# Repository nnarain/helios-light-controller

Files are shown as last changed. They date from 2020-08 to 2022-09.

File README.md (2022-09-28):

# Helios Light Controller




ESP32 based light strip controller.

Usage
-----

TODO

Hardware
--------

This repo contains schematics and PCB layouts for the ESP light controller.

Install submodules to pull in external KiCAD libraries.

```
$ git submodule update --init --recursive
```

Checkout the [release](https://github.com/nnarain/helios-light-controller/releases) page for KiCAD outputs.

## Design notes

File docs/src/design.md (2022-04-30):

# Design

Full schematics can be viewed here: {{#find schematic}}

To see the bill of materials click here: {{#find ibom}}

{{#find schematic_svg}}

{{#find pcb_top}}

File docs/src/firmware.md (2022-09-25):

For full functionality, some WLED usermods must be initialized.

Use the following platformio overrides:

```ini
[platformio]
default_envs = esp32dev

[env:esp32dev]
board = esp32dev
platform = ${esp32.platform}
platform_packages = ${esp32.platform_packages}
build_unflags = ${common.build_unflags}
build_flags = ${common.build_flags_esp32}
             -D WLED_RELEASE_NAME=ESP32
             -D USERMOD_DALLASTEMPERATURE
             -D USERMOD_DALLASTEMPERATURE_CELSIUS
             -D USERMOD_PWM_FAN
             -D PWM_PIN=16
             -D TACHO_PIN=17
lib_deps = ${esp32.lib_deps}
monitor_filters = esp32_exception_decoder
board_build.partitions = ${esp32.default_partitions}
```

Build the firmware then upload to the controllers (note right now the auto-reset does not work, so put the controller in download mode using the BOOT button)

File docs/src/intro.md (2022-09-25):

# Intro

Helios is a ESP32 based smart LED controller intended to work with [WLED](https://kno.wled.ge/) firmware.

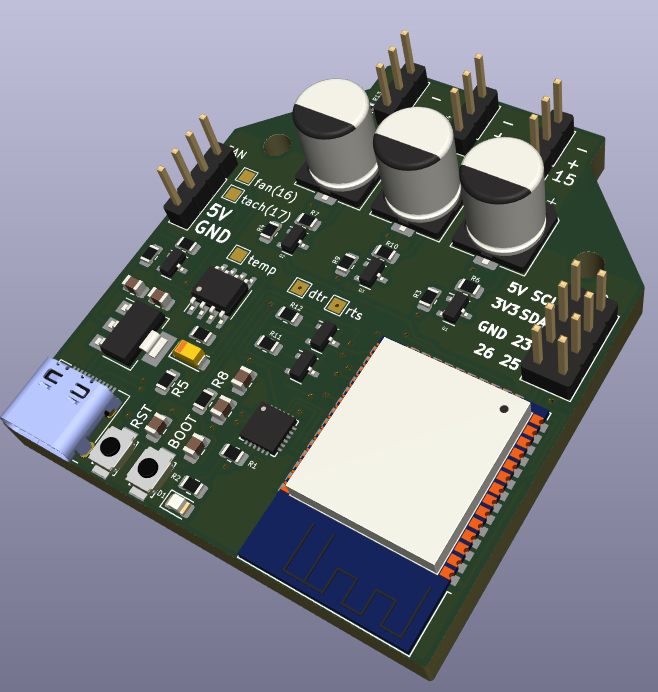
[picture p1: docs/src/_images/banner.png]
image not found!


It features:

* 3x 5V LED output channels
* A PWM fan header (with tachometer feedback)
* I2C and 3x IO breakout
* A USB-C connector and onboard USB-UART adaptor

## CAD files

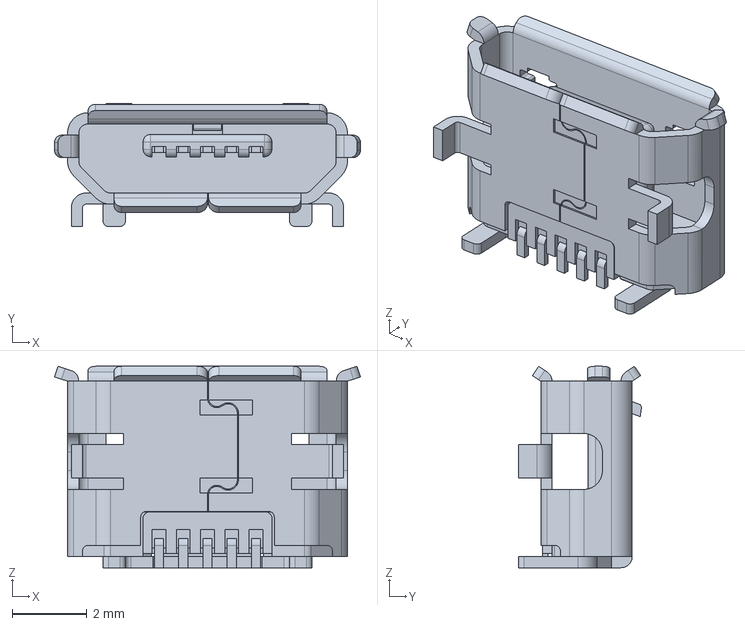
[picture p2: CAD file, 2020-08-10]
design/helios-light-controller/models/usb-b-micro-1050170001.stp
8.20 x 3.30 x 5.40 mm

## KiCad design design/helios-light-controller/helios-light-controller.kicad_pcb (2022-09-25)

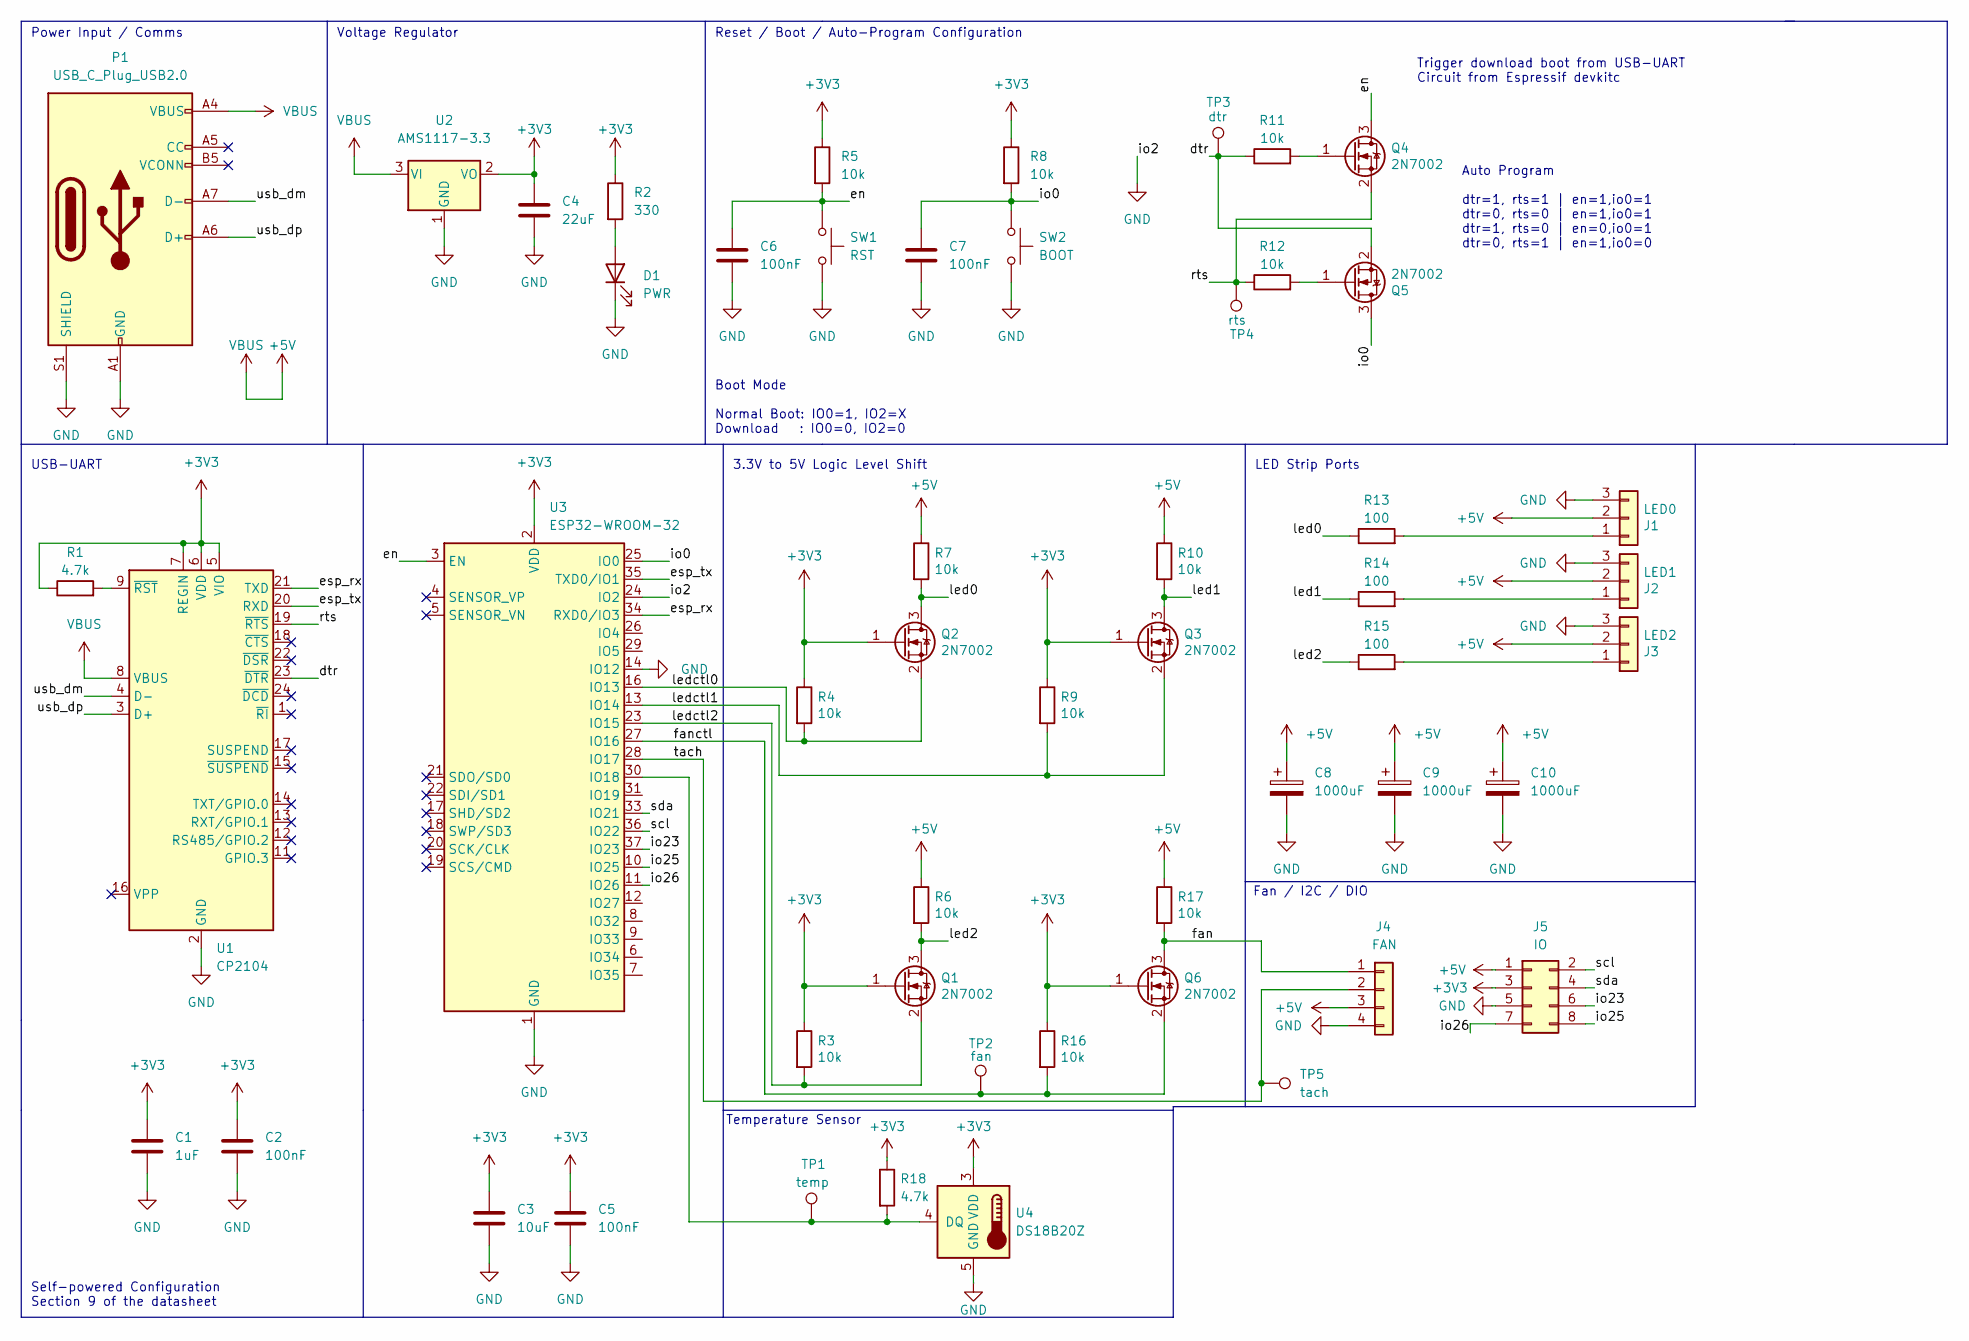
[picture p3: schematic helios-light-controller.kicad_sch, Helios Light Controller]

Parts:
C1: 1uF; C_0805_2012Metric; LCSC C28323
C2, C5, C6, C7: 100nF; C_0805_2012Metric; LCSC C28233
C3: 10uF; C_0805_2012Metric; LCSC C1710
C4: 22uF; CP_EIA-3216-18_Kemet-A; LCSC C116575
C8, C9, C10: 1000uF; CP_Elec_8x10; LCSC C134755
D1: PWR; LED_0805_2012Metric; LCSC C434432
J1: LED0; PinHeader_1x03_P2.54mm_Vertical
J2: LED1; PinHeader_1x03_P2.54mm_Vertical
J3: LED2; PinHeader_1x03_P2.54mm_Vertical
J4: FAN; PinHeader_1x04_P2.54mm_Vertical
J5: IO; PinHeader_2x04_P2.54mm_Vertical
P1: USB_C_Plug_USB2.0; TYPE-C-31-M-04; LCSC C129018
Q1, Q2, Q3, Q4, Q5, Q6: 2N7002; SOT-23; LCSC C8545
R1, R18: 4.7k; R_0805_2012Metric; LCSC C17673
R2: 330; R_0805_2012Metric; LCSC C17630
R3, R4, R5, R6, R7, R8, R9, R10, R11, R12, R16, R17: 10k; R_0805_2012Metric; LCSC C17414
R13, R14, R15: 100; R_0805_2012Metric; LCSC C17408
SW1: RST; TS-1088-AR02016; LCSC C720477
SW2: BOOT; TS-1088-AR02016; LCSC C720477
TP1: temp; TestPoint_Pad_1.5x1.5mm
TP2: fan; TestPoint_Pad_1.5x1.5mm
TP3: dtr; TestPoint_Pad_1.5x1.5mm
TP4: rts; TestPoint_Pad_1.5x1.5mm
TP5: tach; TestPoint_Pad_1.5x1.5mm
U1: CP2104; QFN-24-1EP_4x4mm_P0.5mm_EP2.6x2.6mm; LCSC C47742
U2: AMS1117-3.3; SOT-223-3_TabPin2; LCSC C6186
U3: ESP32-WROOM-32; LCSC C82899
U4: DS18B20Z; SOIC-8_3.9x4.9mm_P1.27mm; LCSC C695837

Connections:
+3V3: C1.1, C2.1, C3.1, C4.1, C5.1, J5.3, Q1.1 (G), Q2.1 (G), Q3.1 (G), Q6.1 (G), R1.1, R2.1, R3.1, R4.1, R5.1, R8.1, R9.1, R16.1, R18.1, U1.5 (VIO), U1.6 (VDD), U1.7 (REGIN), U2.2 (VO), U3.2 (VDD), U4.3 (VDD)
+5V: C8.1, C9.1, C10.1, J1.2, J2.2, J3.2, J4.3, J5.1, P1.A4 (VBUS), P1.A9 (VBUS), P1.B4 (VBUS), P1.B9 (VBUS), R6.1, R7.1, R10.1, R17.1, U1.8 (VBUS), U2.3 (VI); also elsewhere on the board
/dtr: Q5.2 (S), R11.1, TP3.1, U1.23 (~DTR)
/en: C6.1, Q4.3 (D), R5.2, SW1.1, U3.3 (EN)
/esp_rx: U1.21 (TXD), U3.34 (RXD0/IO3)
/esp_tx: U1.20 (RXD), U3.35 (TXD0/IO1)
/fan: J4.1, Q6.3 (D), R17.2; also elsewhere on the board
/fanctl: Q6.2 (S), R16.2, TP2.1, U3.27 (IO16)
/io0: C7.1, Q5.3 (D), R8.2, SW2.1, U3.25 (IO0)
/io23: J5.6, U3.37 (IO23)
/io25: J5.8, U3.10 (IO25)
/io26: J5.7, U3.11 (IO26)
/led0: Q2.3 (D), R7.2, R13.1
/led1: Q3.3 (D), R10.2, R14.1
/led2: Q1.3 (D), R6.2, R15.1
/ledctl0: Q2.2 (S), R4.2, U3.16 (IO13)
/ledctl1: Q3.2 (S), R9.2, U3.13 (IO14)
/ledctl2: Q1.2 (S), R3.2, U3.23 (IO15)
/rts: Q4.2 (S), R12.1, TP4.1, U1.19 (~RTS)
/scl: J5.2, U3.36 (IO22)
/sda: J5.4, U3.33 (IO21)
/tach: J4.2, TP5.1, U3.28 (IO17); also elsewhere on the board
/usb_dm: P1.A7 (D-), U1.4 (D-)
/usb_dp: P1.A6 (D+), U1.3 (D+)
GND: C1.2, C2.2, C3.2, C4.2, C5.2, C6.2, C7.2, C8.2, C9.2, C10.2, D1.1 (K), J1.3, J2.3, J3.3, J4.4, J5.5, P1.A1 (GND), P1.A12 (GND), P1.B1 (GND), P1.B12 (GND), P1.S1 (SHIELD), SW1.2, SW2.2, U1.2 (GND), U1.25 (GND), U2.1 (GND), U3.1 (GND), U3.14 (IO12), U3.15 (GND), U3.24 (IO2), U3.38 (GND), U3.39 (GND), U4.5 (GND); also elsewhere on the board
unnamed: D1.2 (A), R2.2
unnamed: J1.1, R13.2
unnamed: J2.1, R14.2
unnamed: J3.1, R15.2
unnamed: Q4.1 (G), R11.2
unnamed: Q5.1 (G), R12.2
unnamed: R1.2, U1.9 (~RST)
unnamed: R18.2, TP1.1, U3.30 (IO18), U4.4 (DQ)

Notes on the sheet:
Power Input / Comms
Auto Program dtr=1, rts=1 | en=1,io0=1 dtr=0, rts=0 | en=1,io0=1 dtr=1, rts=0 | en=0,io0=1 dtr=0, rts=1 | en=1,io0=0
LED Strip Ports
Self-powered Configuration Section 9 of the datasheet
Temperature Sensor
Fan / I2C / DIO
Trigger download boot from USB-UART Circuit from Espressif devkitc
Reset / Boot / Auto-Program Configuration
USB-UART
Boot Mode Normal Boot: IO0=1, IO2=X Download : IO0=0, IO2=0
3.3V to 5V Logic Level Shift
Voltage Regulator

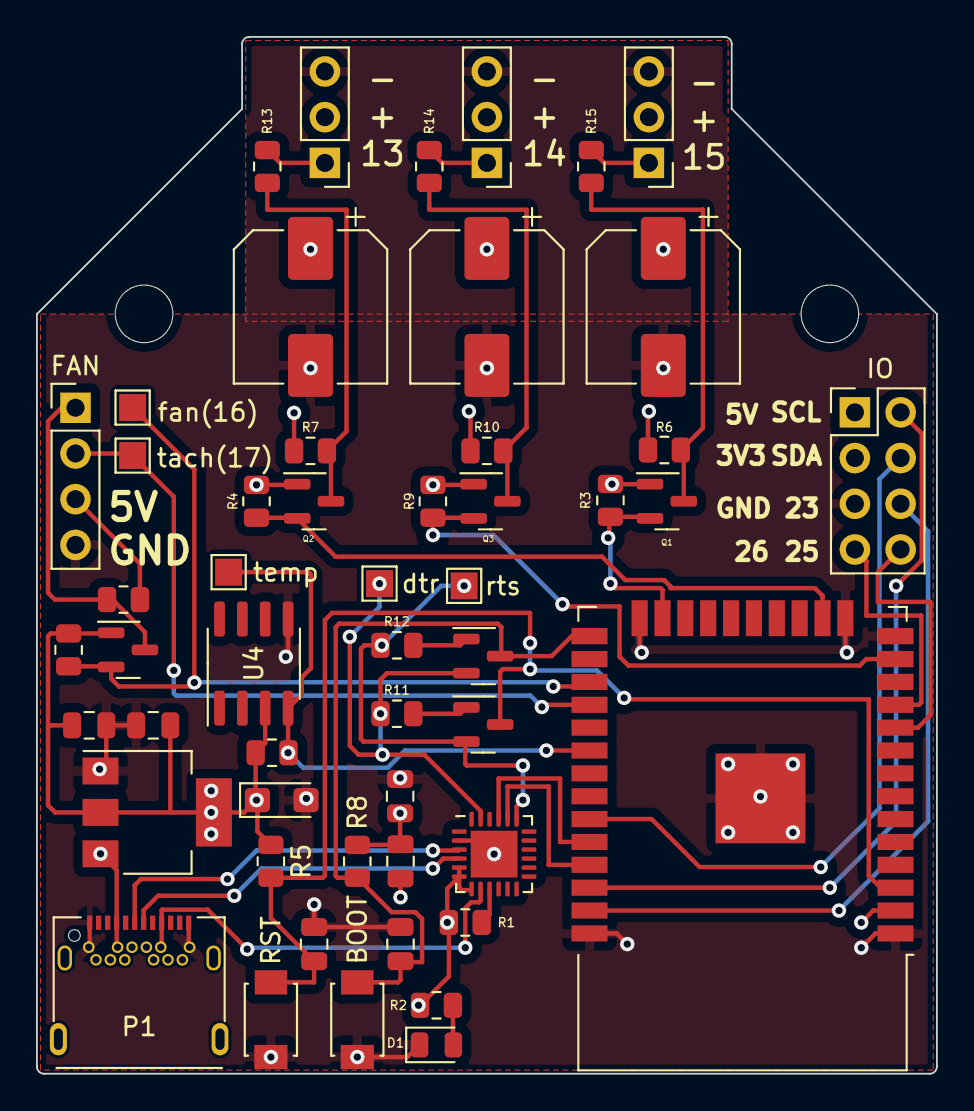
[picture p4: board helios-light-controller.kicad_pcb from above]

Board: 4 copper layers, 50.0 x 57.6 mm, 52 parts (0 on the bottom side), 33 nets.

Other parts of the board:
FAN: FAN; PinHeader_1x04_P2.54mm_Vertical

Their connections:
+5V: FAN.3; also elsewhere on the board
/fan: FAN.1; also elsewhere on the board
/tach: FAN.2; also elsewhere on the board
GND: FAN.4; also elsewhere on the board

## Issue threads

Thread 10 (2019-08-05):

Move ESP01 KiCAD files into repo

nnarain, 2019-08-05:
Currently they use the absolute path on my system,

nnarain, 2019-08-05:
KiCAD project should use relative paths for libraries.

nnarain, 2019-08-05:
Relative paths might not be an option. If not https://aurabindo.in/kicad-tip-component-libraries/

Closed 2019-08-05.

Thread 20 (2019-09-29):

Include ESP8266 KiCAD library in automatic builds

nnarain, 2019-09-29:

nnarain, 2019-10-08:
Resolved by #29.

Closed 2019-10-08.

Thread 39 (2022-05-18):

MTDI (GPIO12) should be pulled down

nnarain, 2022-05-18:
This is one of the "strapping" pins and is used to configure the SPI flash. Currently this is pulled up for one of the level shifters which configures the SPI flash for 1.8V instead of 3.3V.

Closed 2022-09-05.

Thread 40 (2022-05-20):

Temperature sensor

nnarain, 2022-05-20:
Onboard temperature sensor

nnarain, 2022-05-20:
https://github.com/Aircoookie/WLED/tree/main/usermods/Temperature

Closed 2022-09-05.

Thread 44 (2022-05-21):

Reverse voltage protection

nnarain, 2022-05-21:

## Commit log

2019-08-04 Resolves #7. Restore light state after power cycle.
2019-08-04 Resolves #8. Added KiCAD files.
    [esp-light-controller.sch]
2019-08-05 Update pinout for USB connector
    [esp-light-controller.sch]
2019-08-05 Resolves #10. Removed use of absolute paths in project settings.
    [esp-light-controller.sch]
2019-08-08 Resolves #11. Added PCB Layout.
    [esp-light-controller.kicad_pcb, esp-light-controller.sch]
2019-09-29 Resolves #13. KiCAD automation
2019-10-01 NOP schematic update..
2019-10-08 Resolves #29. Added third party KiCAD as a submodule.
    [esp-light-controller.sch]
2020-07-28 Update to surface mount components
    [esp-light-controller.kicad_pcb, esp-light-controller.sch]
2020-07-30 Version 2 design
    [esp-light-controller.kicad_pcb, esp-light-controller.sch, usb-b-micro-1050170001.stp]
2020-08-10 ESPHome example. Remove arduino firmware.
2022-04-14 Update to kicad 6
    [esp-light-controller.kicad_sch]
2022-04-30 ESP32 based design
    [esp-light-controller.kibot.yaml, esp-light-controller.kicad_pcb, esp-light-controller.kicad_sch]
2022-05-01 update pwr led to more available part
    [esp-light-controller.kicad_sch]
2022-05-06 Resolves #38. Select USB-C Connector that works for JLCPCB assembly
    [esp-light-controller.kicad_pcb, esp-light-controller.kicad_sch]
2022-05-08 Restore silkscreen part references
    [esp-light-controller.kicad_pcb]
2022-09-05 Resolves #39, #40, #43. Rev D.
    [esp-light-controller.kicad_pcb, esp-light-controller.kicad_sch]
2022-09-05 M3 mounting holes
    [esp-light-controller.kicad_pcb]
2022-09-05 Fix datasheet for fan header
    [esp-light-controller.kicad_sch]
2022-09-25 rev e
    [esp-light-controller.kicad_pcb, esp-light-controller.kicad_sch]
2022-09-25 remove datasheet from io header
    [esp-light-controller.kicad_sch]
2022-09-28 Rename project
    [esp-light-controller.sch, helios-light-controller.kibot.yaml, helios-light-controller.kicad_pcb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]
